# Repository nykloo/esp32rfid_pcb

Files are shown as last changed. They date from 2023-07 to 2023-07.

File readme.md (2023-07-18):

### ESP32 rfid circuit 
## 125khz rfid reader/writer for EM4x chips
### Works for kyber crystals
## Firmware
https://github.com/nykloo/ESP32RFID-Firmware
## Control App
https://github.com/nykloo/ESP32RFID-App
## IMPORTANT NOTES
+ C_RESA1, C_RESB1,C_DV1, C_DV2 should be fairly close to their intended values (ie use capicitors with a tolerance of less than 5%) Alternatively the optional capacitors can be used to more  tune the resonate frequency of the antenna circuit. 
+ The PCB coil antenna is designed to printed on a pcb with thickness of 1mm and outer copper weight of 1 oz. I have been ordering these from jlc pcb.

## Schematic
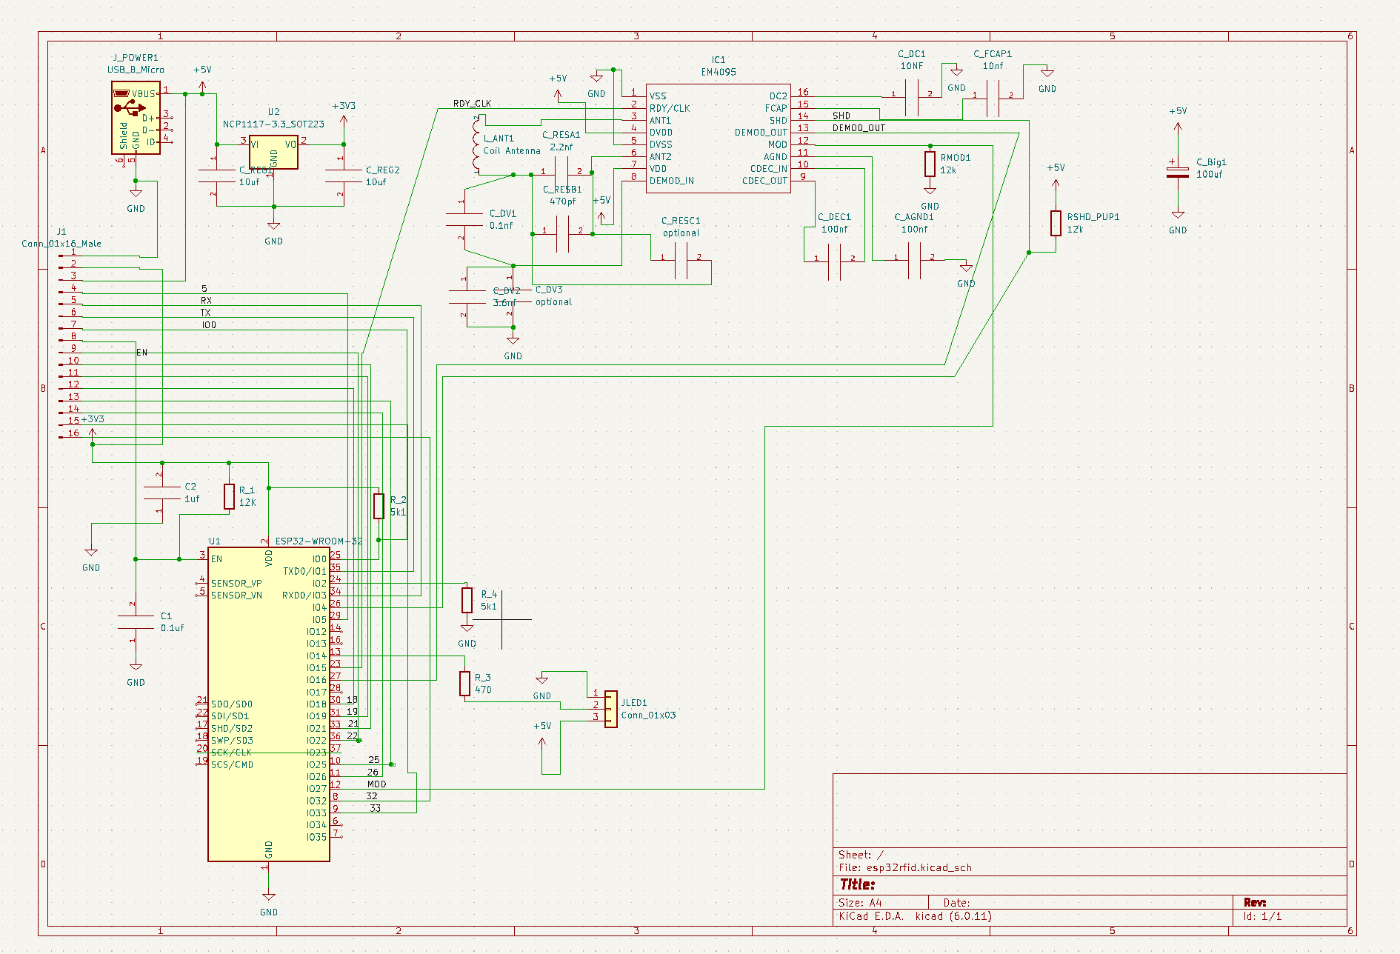
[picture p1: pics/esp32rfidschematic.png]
pcb schematic schematic


## PCB
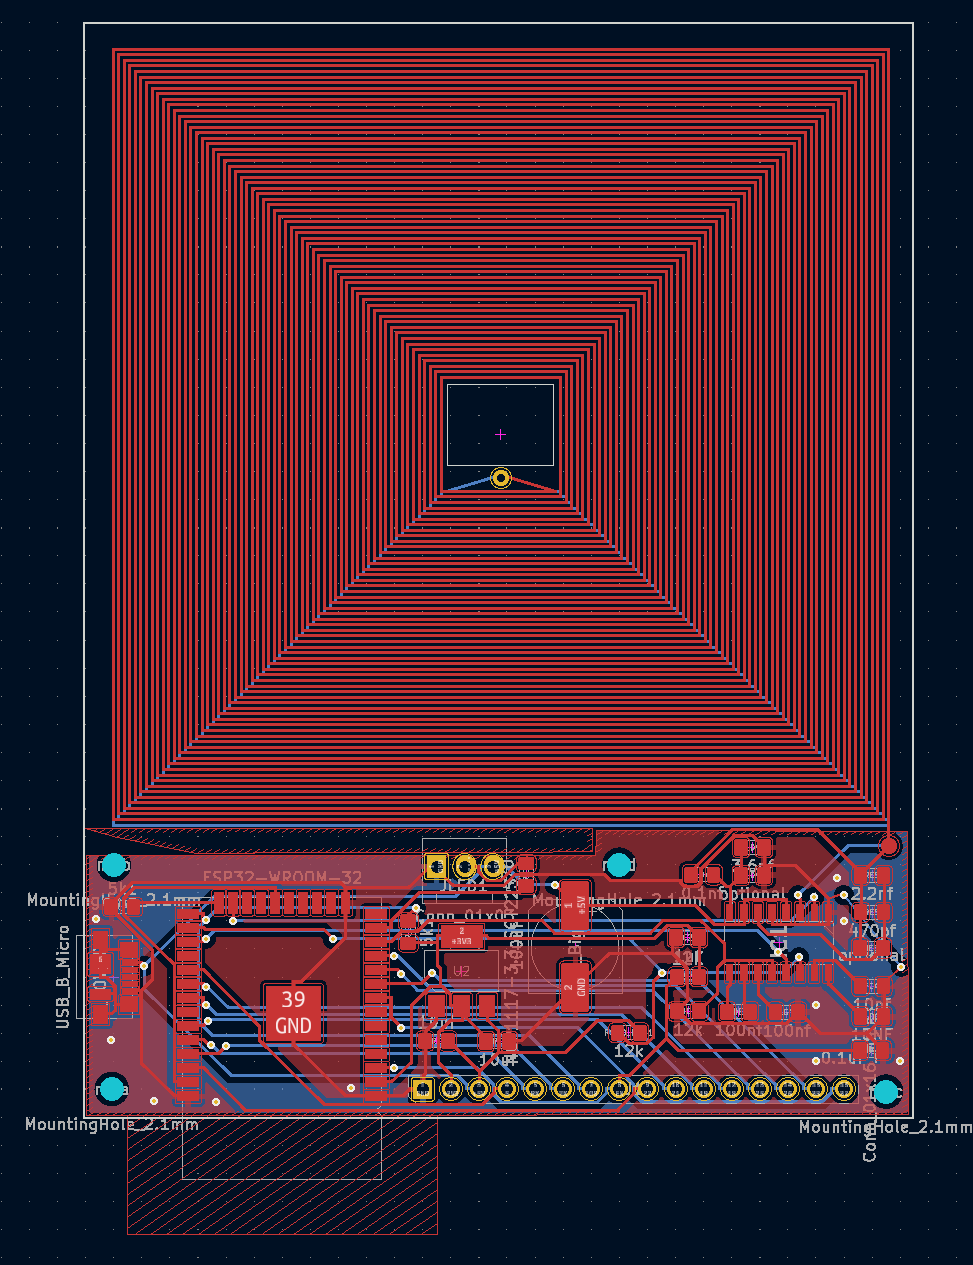
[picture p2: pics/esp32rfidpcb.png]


## Assembly
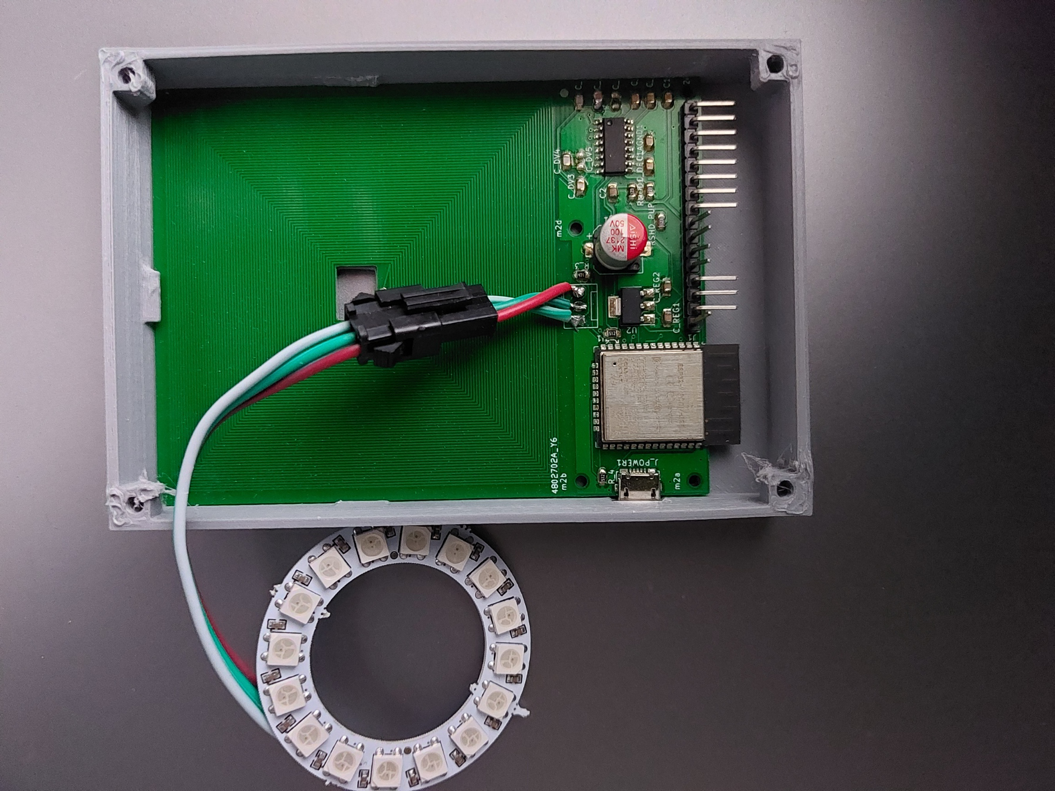
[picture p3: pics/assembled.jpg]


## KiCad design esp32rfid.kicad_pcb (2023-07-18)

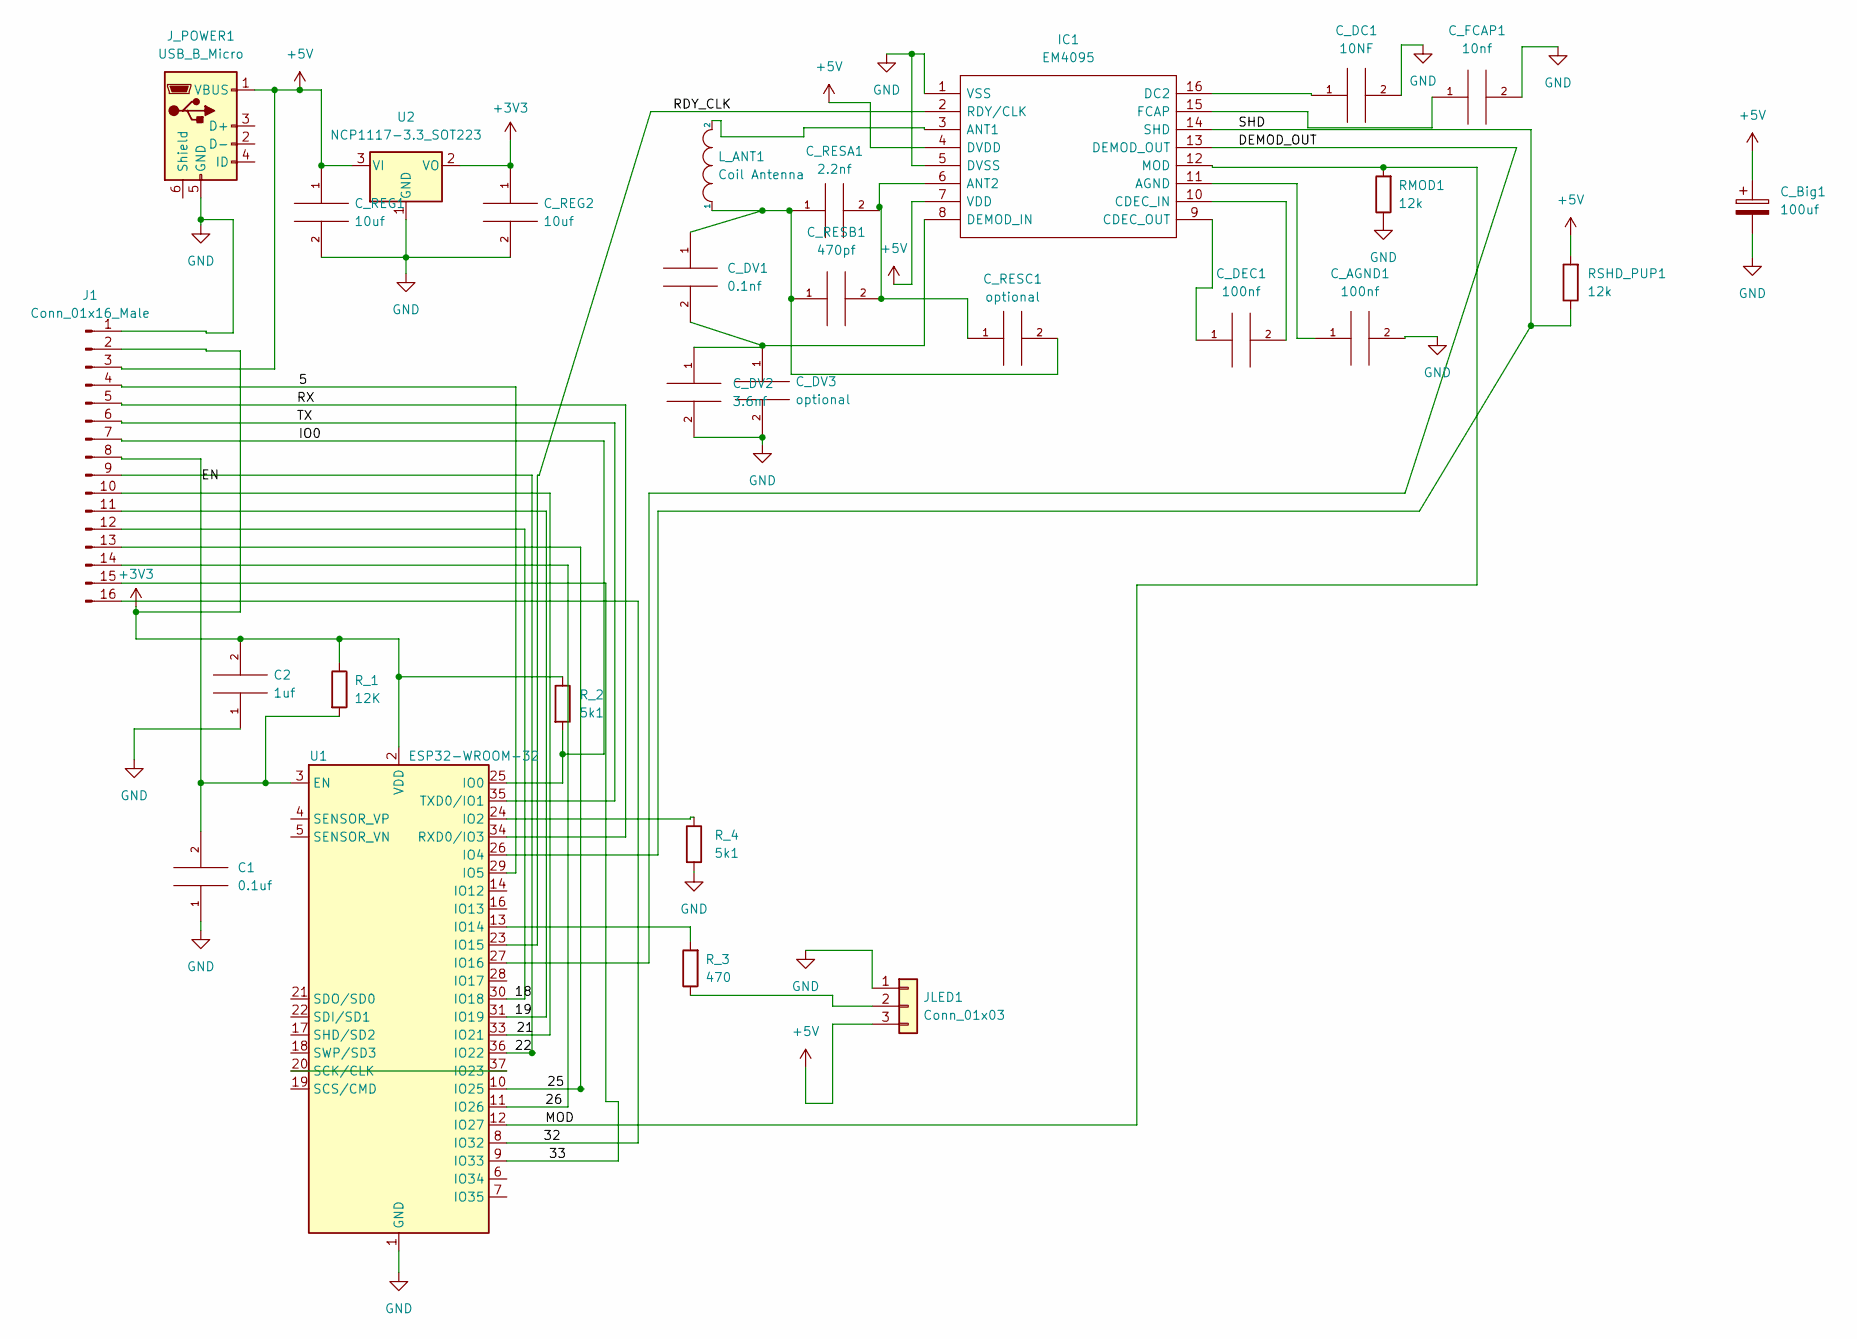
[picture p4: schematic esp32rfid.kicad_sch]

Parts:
C1: 0.1uf; C_0805_2012Metric_Pad1.18x1.45mm_HandSolder
C2: 1uf; C_0805_2012Metric_Pad1.18x1.45mm_HandSolder
C_AGND1: 100nf; C_0805_2012Metric_Pad1.18x1.45mm_HandSolder
C_Big1: 100uf; CP_Elec_8x10.5
C_DC1: 10NF; C_0805_2012Metric_Pad1.18x1.45mm_HandSolder
C_DEC1: 100nf; C_0805_2012Metric_Pad1.18x1.45mm_HandSolder
C_DV1: 0.1nf; C_0805_2012Metric_Pad1.18x1.45mm_HandSolder
C_DV2: 3.6nf; C_0805_2012Metric_Pad1.18x1.45mm_HandSolder
C_DV3: optional; C_0805_2012Metric_Pad1.18x1.45mm_HandSolder
C_FCAP1: 10nf; C_0805_2012Metric_Pad1.18x1.45mm_HandSolder
C_REG1, C_REG2: 10uf; C_0805_2012Metric_Pad1.18x1.45mm_HandSolder
C_RESA1: 2.2nf; C_0805_2012Metric_Pad1.18x1.45mm_HandSolder
C_RESB1: 470pf; C_0805_2012Metric_Pad1.18x1.45mm_HandSolder
C_RESC1: optional; C_0805_2012Metric_Pad1.18x1.45mm_HandSolder
IC1: EM4095; SOIC127P602X173-16N; Manufacturer_Part_Number EM4095
J1: Conn_01x16_Male; PinHeader_1x16_P2.54mm_Vertical
JLED1: Conn_01x03; FanPinHeader_1x03_P2.54mm_Vertical
J_POWER1: USB_B_Micro; USB_Micro-B_Molex_47346-0001
L_ANT1: Coil Antenna; 60_turn_square_inductor_corrected
RMOD1: 12k; R_0805_2012Metric_Pad1.20x1.40mm_HandSolder
RSHD_PUP1: 12k; R_0805_2012Metric_Pad1.20x1.40mm_HandSolder
R_1: 12K; R_0805_2012Metric_Pad1.20x1.40mm_HandSolder
R_2, R_4: 5k1; R_0805_2012Metric_Pad1.20x1.40mm_HandSolder
R_3: 470; R_0805_2012Metric_Pad1.20x1.40mm_HandSolder
U1: ESP32-WROOM-32
U2: NCP1117-3.3_SOT223; SOT-223-3_TabPin2

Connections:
+3V3: C2.2, C_REG2.1, J1.2, R_1.1, R_2.1, U1.2 (VDD), U2.2 (VO)
+5V: C_Big1.1, C_REG1.1, IC1.4 (DVDD), IC1.7 (VDD), J1.3, JLED1.3, J_POWER1.1 (VBUS), RSHD_PUP1.2, U2.3 (VI)
/5: J1.4, U1.29 (IO5)
/18: J1.12, U1.30 (IO18)
/19: J1.11, U1.31 (IO19)
/21: J1.10, U1.33 (IO21)
/22: J1.9, U1.36 (IO22)
/25: J1.13, U1.10 (IO25)
/26: J1.14, U1.11 (IO26)
/32: J1.16, U1.8 (IO32)
/33: J1.15, U1.9 (IO33)
/DEMOD_OUT: IC1.13 (DEMOD_OUT), U1.27 (IO16)
/EN: C1.2, J1.8, R_1.2, U1.3 (EN)
/IO0: J1.7, R_2.2, U1.25 (IO0)
/MOD: IC1.12 (MOD), RMOD1.2, U1.12 (IO27)
/RDY_CLK: IC1.2 (RDY/CLK), U1.23 (IO15)
/RX: J1.5, U1.34 (RXD0/IO3)
/SHD: IC1.14 (SHD), RSHD_PUP1.1, U1.26 (IO4)
/TX: J1.6, U1.35 (TXD0/IO1)
GND: C1.1, C2.1, C_AGND1.2, C_Big1.2, C_DC1.2, C_DV2.2, C_DV3.2, C_FCAP1.2, C_REG1.2, C_REG2.2, IC1.1 (VSS), IC1.5 (DVSS), J1.1, JLED1.1, J_POWER1.5 (GND), RMOD1.1, R_4.2, U1.1 (GND), U1.15 (GND), U1.38 (GND), U1.39 (GND), U2.1 (GND)
unnamed: C_AGND1.1, IC1.11 (AGND)
unnamed: C_DC1.1, IC1.16 (DC2)
unnamed: C_DEC1.1, IC1.9 (CDEC_OUT)
unnamed: C_DEC1.2, IC1.10 (CDEC_IN)
unnamed: C_DV1.1, C_RESA1.1, C_RESB1.1, C_RESC1.2, L_ANT1.1
unnamed: C_DV1.2, C_DV2.1, C_DV3.1, IC1.8 (DEMOD_IN)
unnamed: C_FCAP1.1, IC1.15 (FCAP)
unnamed: C_RESA1.2, C_RESB1.2, C_RESC1.1, IC1.6 (ANT2)
unnamed: IC1.3 (ANT1), L_ANT1.2
unnamed: JLED1.2, R_3.1
unnamed: R_3.2, U1.13 (IO14)
unnamed: R_4.1, U1.24 (IO2)
unnamed: U1.20 (SCK/CLK), U1.37 (IO23)

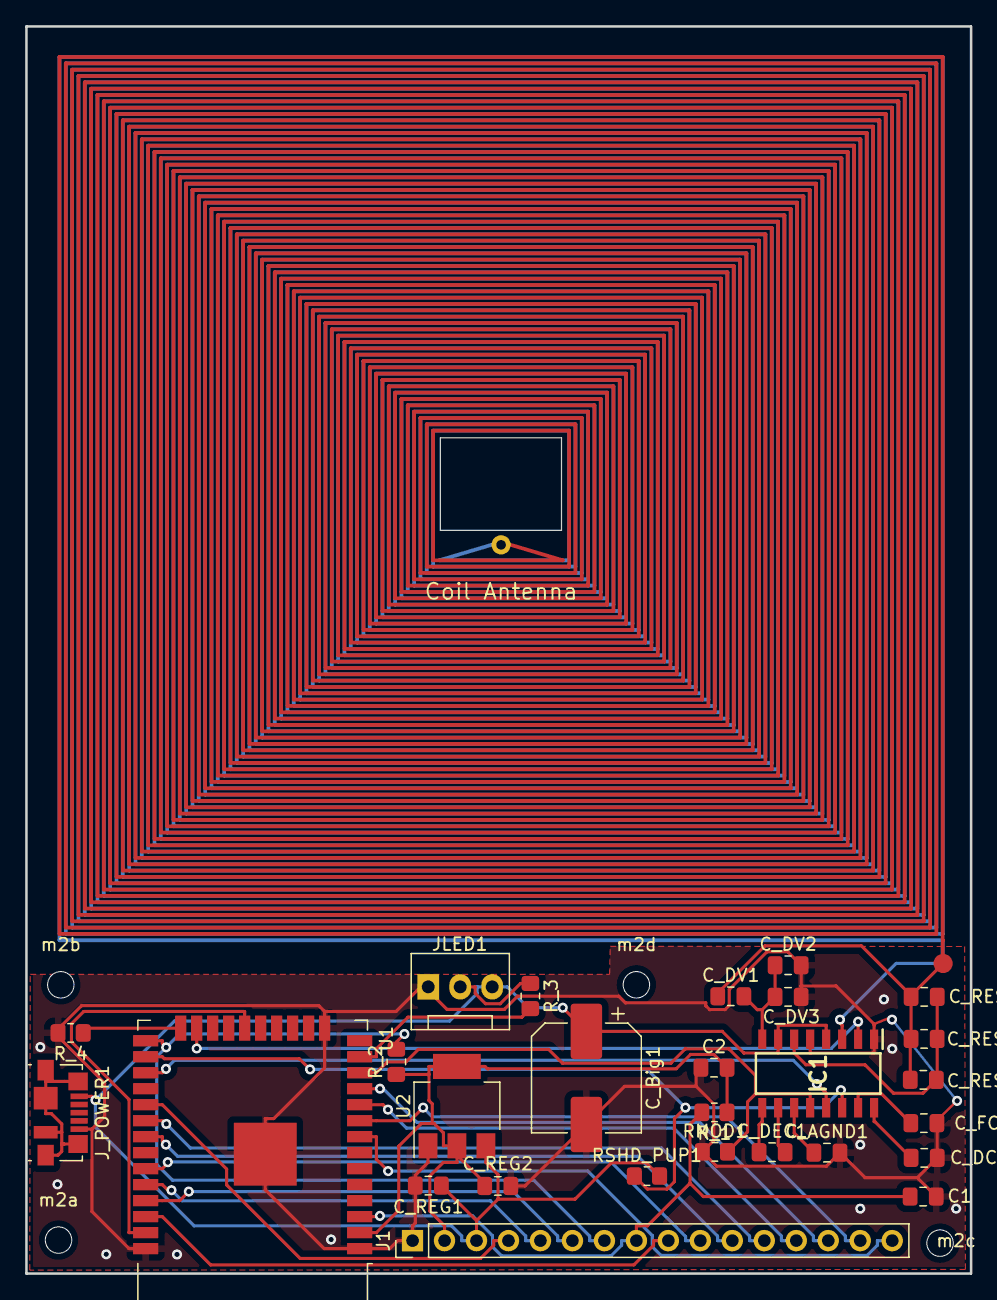
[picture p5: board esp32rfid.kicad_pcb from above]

Board: 2 copper layers, 75.0 x 99.1 mm, 32 parts (0 on the bottom side), 33 nets.

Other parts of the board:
m2a, m2b, m2c, m2d: MountingHole_2.1mm

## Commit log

2022-09-13 created schematic
    [attiny_rfid_light.kicad_pcb, attiny_rfid_light.kicad_sch]
2022-10-21 va plus alittle
    [attiny_rfid_light-B_Cu.gbl, attiny_rfid_light-B_Cu.gbr, attiny_rfid_light-B_Mask.gbr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]
2022-10-21 Update fix antenna direction and missing shd trace
    [attiny_rfid_light.kicad_pcb, attiny_rfid_light.kicad_sch, espboardpreroutev2.dsn]
2022-11-12 updated values to match place values
    [attiny_rfid_light.kicad_sch, attiny_rfid_lightbackup11122020.kicad_pcb]
2023-07-18 Clean up and prep for release
    [attiny_rfid_light-B_Cu.gbl, attiny_rfid_light-B_Cu.gbr, attiny_rfid_light-B_Mask.gbr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]
